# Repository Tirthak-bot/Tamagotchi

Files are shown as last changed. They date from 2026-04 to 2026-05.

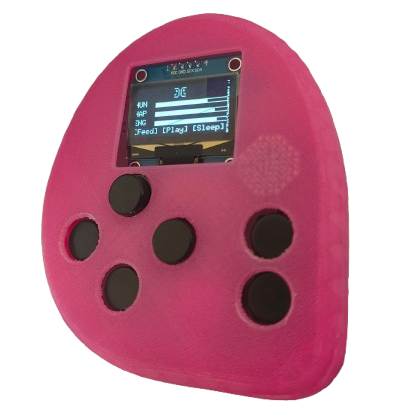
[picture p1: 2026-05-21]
Renders/IRL Images/IMG_20260521_132635066-removebg-preview.png

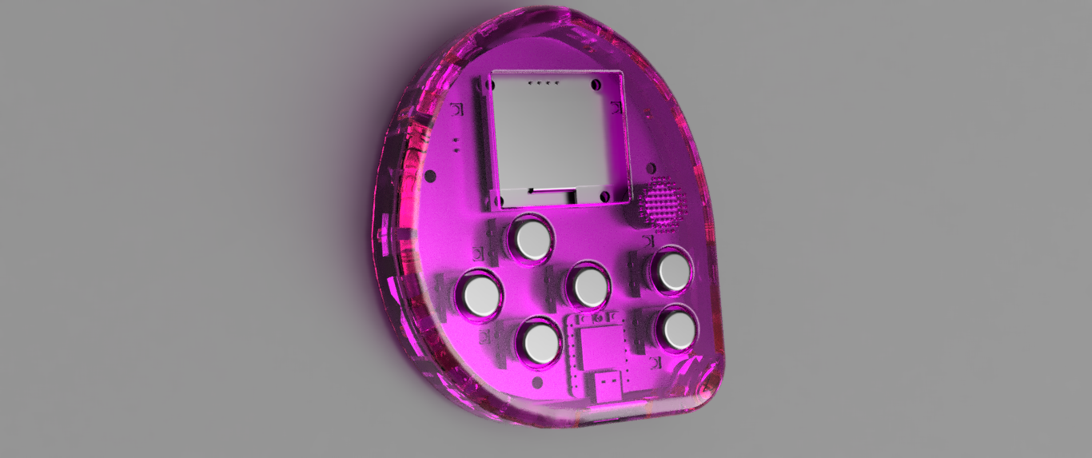
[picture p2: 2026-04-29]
Renders/Render 2.png

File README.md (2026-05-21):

# Tamagotchi

A Custom Tanmagotchi made using The Xiao ESP32 C3. <br>
Designed in KiCad and Fusion 360!

Beige Pink Retro Game Arcade Poster (1)

<br>
<br>

||IRL IMAGES||
|----|----|----|
|IMG_20260521_132635066-removebg-preview| | IMG_20260520_202827706 (1)|

||RENDERS||
|----|----|----|
|Render 1 edited | Render 2 edited | Render 4 edited |

<br>
The irl build looks a bit weird because i couldn't get my hands on the PCB so i had to handwire it sobbbb.
 <br>
 <br>
Using this is pretty straight forward, connect the Tamagotchi to Arduino IDE, Select the board as Xiao ESP32 C3 and Flash the Firmware! 
<br>
The Battery on this should last around 15 hrs :>
<br>
<br>
I wanna build a Tamagotchi because i never had one and what's the fun in buying one!
<br>
<br> 
Demo Video: https://youtube.com/shorts/sFA_lzHIbYA?feature=share

# Schematic
Tamagotchi Schematic

# PCB
Tamagotchi PCB

# Case

The two halfs of the case are joined using magnets and the PCB is screwed into the Bottom case using M3 screws.

Render 5

# Firmware

The firmware is written in C++ and will be edited/deployed from Arduino IDE.

# BOM

| SR.NO | ITEM | QUANTITY | UNIT PRICE | TOTAL PRICE | URL |
|---|---|---|---|---|---|
|1.|Xiao ESP32 C3|1|₹599 ($6.31)|₹650 ($6.85) (Including Shipping)|https://robocraze.com/products/seeed-studio-xiao-esp32c3|
|2.|1.3 inch I2C OLED Display|1|₹320 ($3.38)|₹370 ($3.90) (Including Shipping)|https://robu.in/product/1-3-inch-i2c-iic-oled-lcd-module-4pin-with-vcc-gnd-white|
|3.|12x12x7.3mm Tactile Push Button|10 (Required 6 but MOQ 10)|₹5.5 ($0.058)|₹55 ($0.58) (Shipping Already included above)|https://robu.in/product/12x12x7-3mm-tactile-push-button-switch-10pcs/|
|4.|12 x 9.5mm 3V Active Electromagnetic Buzzer|1|₹14 ($0.15)|₹14 ($0.15) (Shipping Already included above)|https://robu.in/product/3v-active-electromagnetic-buzzer-pack-of-5/|
|5.|1000mAh Rechargeable 3.7v LiPo Battery|1|₹311 ($3.28)|₹311 ($3.28) (Shipping Already included above)|https://robocraze.com/products/witty-fox-1000mah-rechargeable-3-7v-lipo-battery|
|6.|SK6812-MINI-E Neopixel LEDs|8|0 (Self Sourced)|0 (Self Sourced)|LCSC Part #C5149201|
|7.|40x2 Pin 2.54mm Pitch Male Berg Strip (To Connect Stuff ofc)|1|₹10 ($0.11)|₹10 ($0.11) (Shipping Already included above)|https://robocraze.com/products/40x2-pin-2-54mm-pitch-male-berg-strip|
|8.|12x12x7.3 mm Round Cap for Square tactile Switch|6|₹3 ($0.032)|₹18 ($0.19) (Shipping Already included above)|https://robu.in/product/12x12x7-3-mm-round-cap-for-square-tactile-switch|
|9.|M3x6 mm Brass Heat Set Inserts|25 (Required 3 but MOQ 25)|₹4.8 ($0.05)| ₹145 ($1.52) (Including shipping and tax|https://onlyscrews.in/products/m3-x-6mm-3d-printing-brass-threaded-inserts-dia-3mm-length-6mm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|
|10.|M3 Hex Screw Set|1|₹240 ($2.52)|₹265 ($2.80) (Including shipping and tax)|https://onlyscrews.in/products/m3-allen-button-head-ss304-assorted-box?variant=50368948863289|
|11.|3X3 mm Round Magnets N35|25|₹9.5 ($0.10)|₹260 ($2.73) (Including shipping and tax)|https://onlyscrews.in/products/3mm-x-3mm-neodymium-disc-magnets-n35-dia-3mm-thickness-3mm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| 
|12.|Lanyard|1|0 (Self Sourced)| 0 (Self Sourced)|https://amzn.in/d/03Kt7OoU|
|13.|Solder Wire 60/40 - 50gm|1|₹219 ($2.31)|₹219 ($2.31) (Shipping Already included above)|https://robocraze.com/products/noel-solder-wire-60-40-50gm-pack|
|14.|3D Printed Case|1|-| ₹50 ($0.53) in Filament (Around 50gms)|I own a 3D Printer yayaya (Will Print it in Pink PLA Translucent)|
|15.|Super Glue (To Stick The Magnets To The Case)|-|0 (Self Sourced)| 0 (Self Sourced)|https://amzn.in/d/032gD5EX|
|16.|PCB (From Aivon PCB)|5 (MOQ)|$0.20| $2.00 (Including Shipping)|In my Cart ofc (Hope that the Price stays the same sobb)|
|17.|Hex Allen Ket Set|1|₹248 ($2.60)|₹275 ($2.90) (Including tax and shipping)|https://onlyscrews.in/products/eastman-9-pcs-hex-allen-key-set?variant=51184779362617|
|||||||
||TOTAL|||₹2850 ($30.00) (Including all taxes and shipping)|

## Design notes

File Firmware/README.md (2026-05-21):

# Firmware
So this uses the U8g2 library for the display, not the normal Adafruit SSD1306 library as i was having some problems with it. <br>
You install it in Arduino IDE like any other library :)

<br>


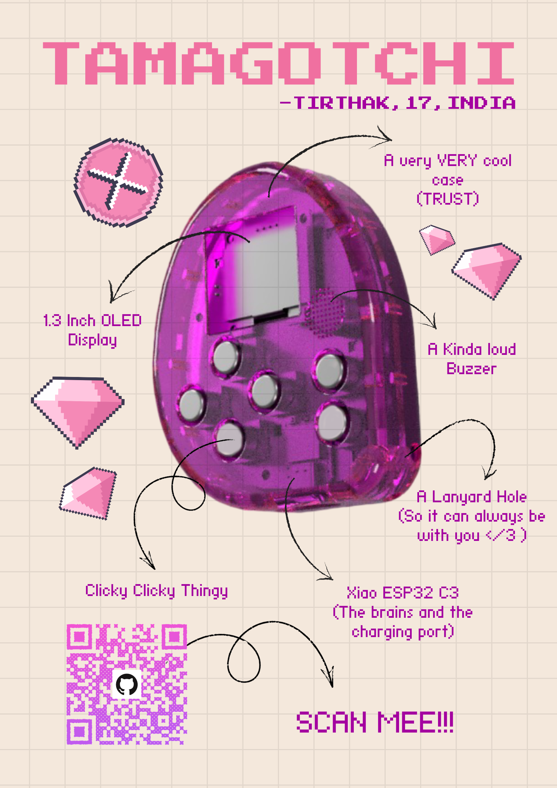
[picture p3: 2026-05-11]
Renders/Tamagotchi Zine Page With Render.png

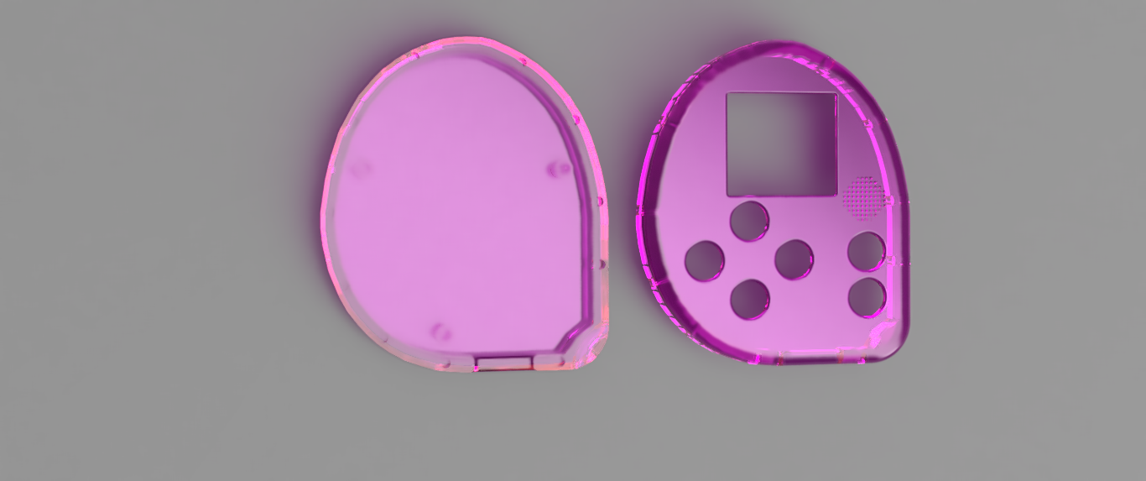
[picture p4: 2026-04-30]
Renders/Render 5.PNG

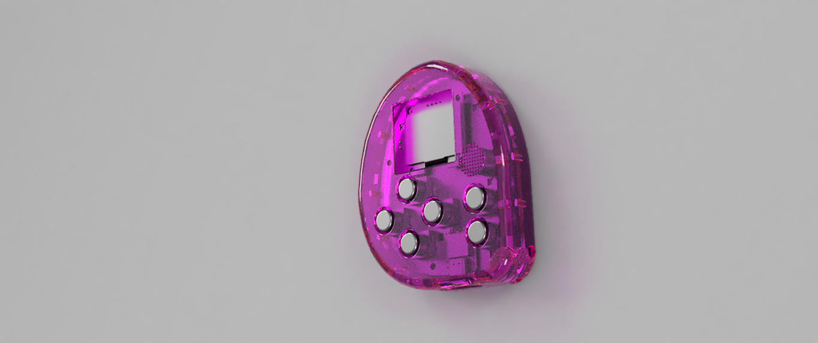
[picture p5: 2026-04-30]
Renders/Render 4.png

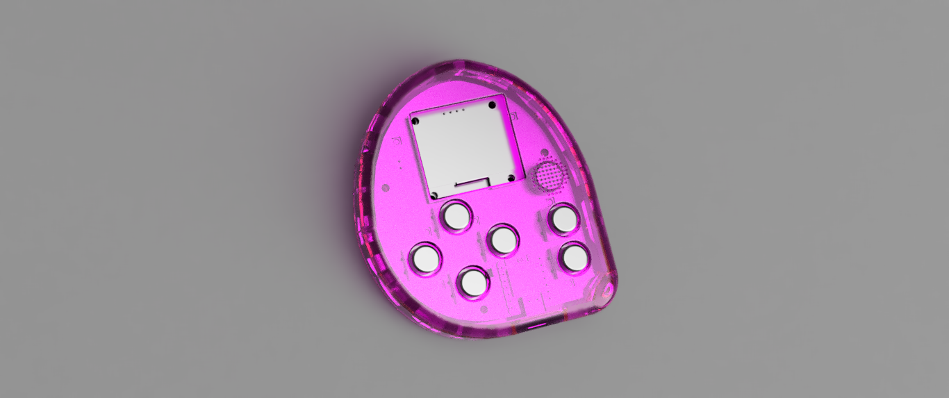
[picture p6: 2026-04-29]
Renders/Render 3.PNG

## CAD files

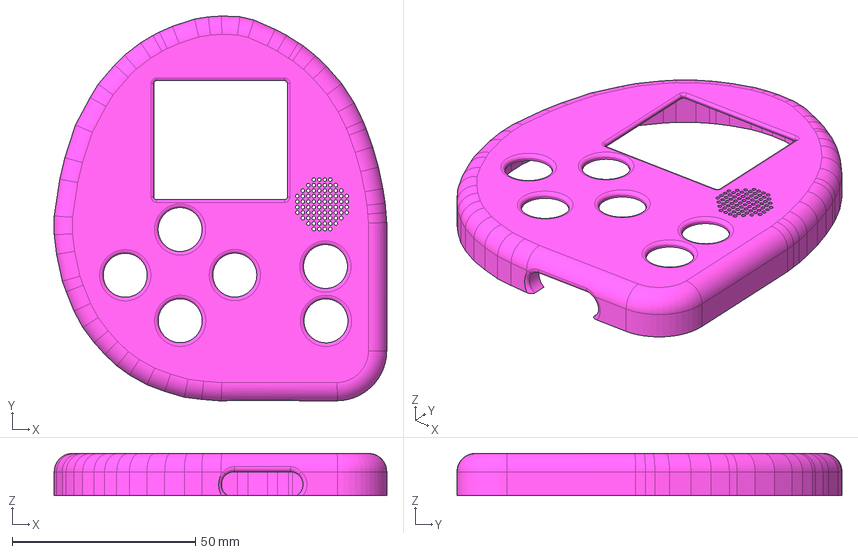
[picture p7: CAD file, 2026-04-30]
CAD/Tamagotchi Case Top.step
90.8 x 105.1 x 11.5 mm

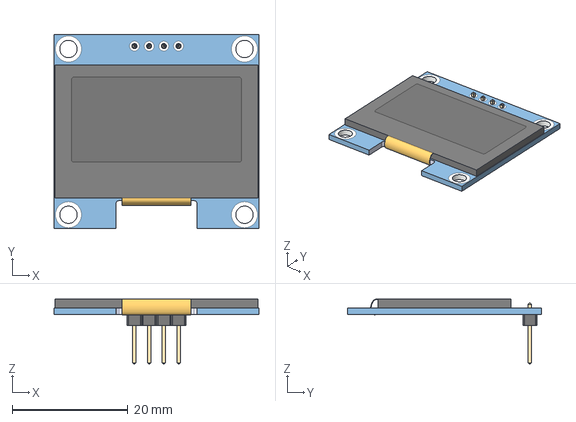
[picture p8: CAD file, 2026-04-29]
Project Resources/1.3 Inch OLED/1.3 Inch OLED 3D Model.stp
35.4 x 33.5 x 11.2 mm

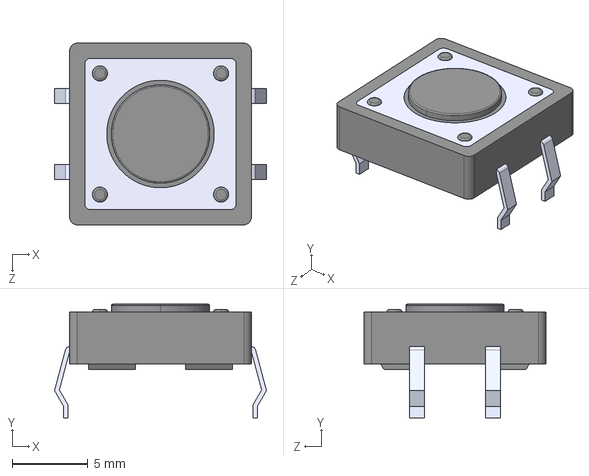
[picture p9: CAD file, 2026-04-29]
Project Resources/12mm x 12mm Tactile Buttons/VS-1213-67-160GF.step
14.0 x 7.50 x 12.0 mm

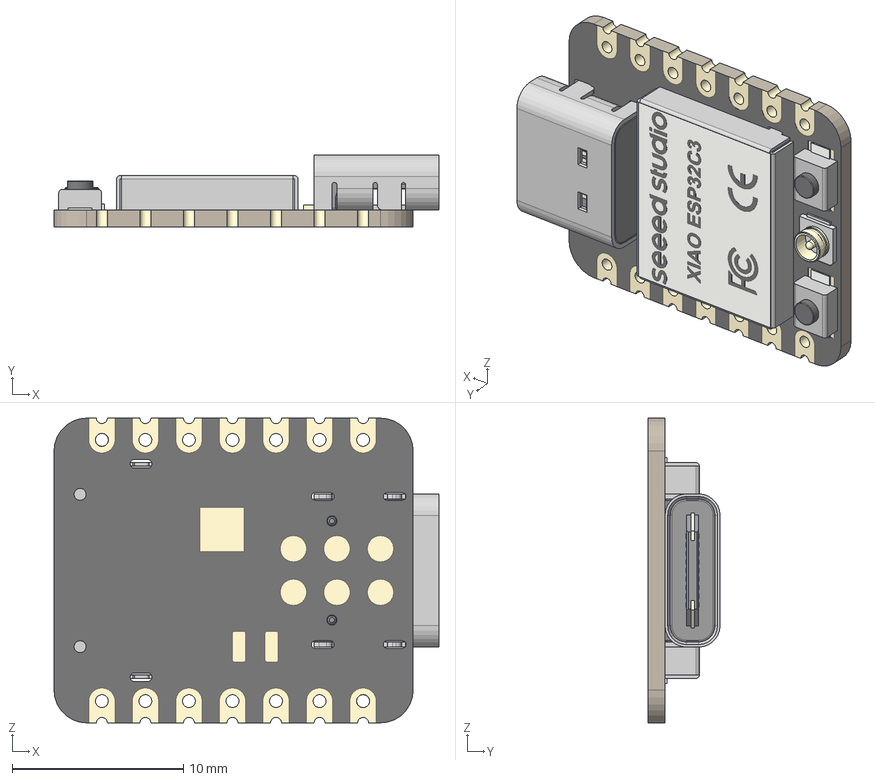
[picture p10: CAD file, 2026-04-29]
Project Resources/Xiao ESP32 C3/seeed-studio-xiao-esp32-c3.step
22.5 x 4.21 x 17.8 mm
BOSS-EXTRUDE14_8_
BOSS-EXTRUDE7_4_
BOSS-EXTRUDE7_3_
BOSS-EXTRUDE14_4_
BOSS-EXTRUDE14_2_
BOSS-EXTRUDE14_11_
BOSS-EXTRUDE7_7_
BOSS-EXTRUDE14_9_
BOSS-EXTRUDE14_3_
BOSS-EXTRUDE14_7_
MIRROR2
BOSS-EXTRUDE14_5_
BOSS-EXTRUDE14_12_
BOSS-EXTRUDE7_8_
BOSS-EXTRUDE7_1_
BOSS-EXTRUDE14_10_
BOSS-EXTRUDE7_9_
BOSS-EXTRUDE14_6_
BOSS-EXTRUDE14_1_
BOSS-EXTRUDE7_6_
BOSS-EXTRUDE7_2_
CUT-EXTRUDE5
BOSS-EXTRUDE7_5_
U.FL Connector v1
Button (1) x 2
Shield

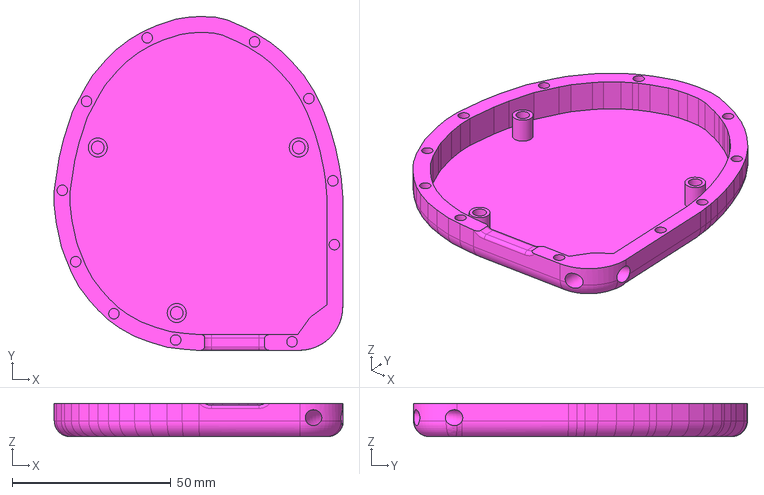
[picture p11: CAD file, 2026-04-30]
CAD/Tamagotchi Case Bottom.step
90.8 x 105.1 x 10.5 mm

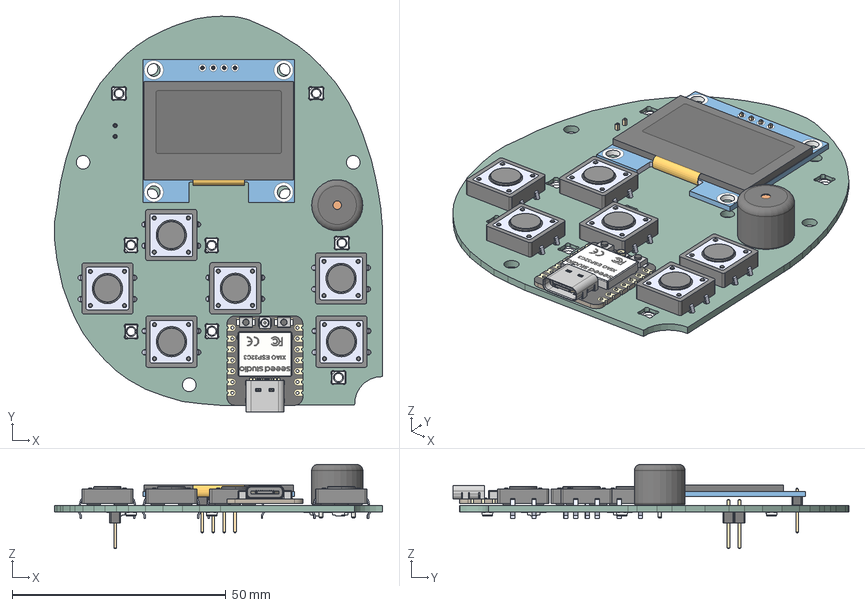
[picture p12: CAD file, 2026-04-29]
CAD/Tamagotchi PCB.step
76.8 x 92.6 x 19.8 mm
SK6812MINI-E--3DModel-STEP-418109 x 8
VS-1213-67-160GF x 6
Buzzer_12x9.5RM7.6
BOSS-EXTRUDE14_8_
BOSS-EXTRUDE7_4_
BOSS-EXTRUDE7_3_
BOSS-EXTRUDE14_4_
BOSS-EXTRUDE14_2_
BOSS-EXTRUDE14_11_
BOSS-EXTRUDE7_7_
BOSS-EXTRUDE14_9_
BOSS-EXTRUDE14_3_
BOSS-EXTRUDE14_7_
MIRROR2
BOSS-EXTRUDE14_5_
BOSS-EXTRUDE14_12_
BOSS-EXTRUDE7_8_
BOSS-EXTRUDE7_1_
BOSS-EXTRUDE14_10_
BOSS-EXTRUDE7_9_
BOSS-EXTRUDE14_6_
BOSS-EXTRUDE14_1_
BOSS-EXTRUDE7_6_
BOSS-EXTRUDE7_2_
CUT-EXTRUDE5
BOSS-EXTRUDE7_5_
U.FL Connector v1
Button (1) x 2
Shield
AZ-Delivery - OLED13 IIC
PinHeader_1x02_P2.54mm_Vertical
Tamagotchi_PCB

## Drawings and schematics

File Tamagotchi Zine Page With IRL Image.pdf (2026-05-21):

# TAMAGOTCHI

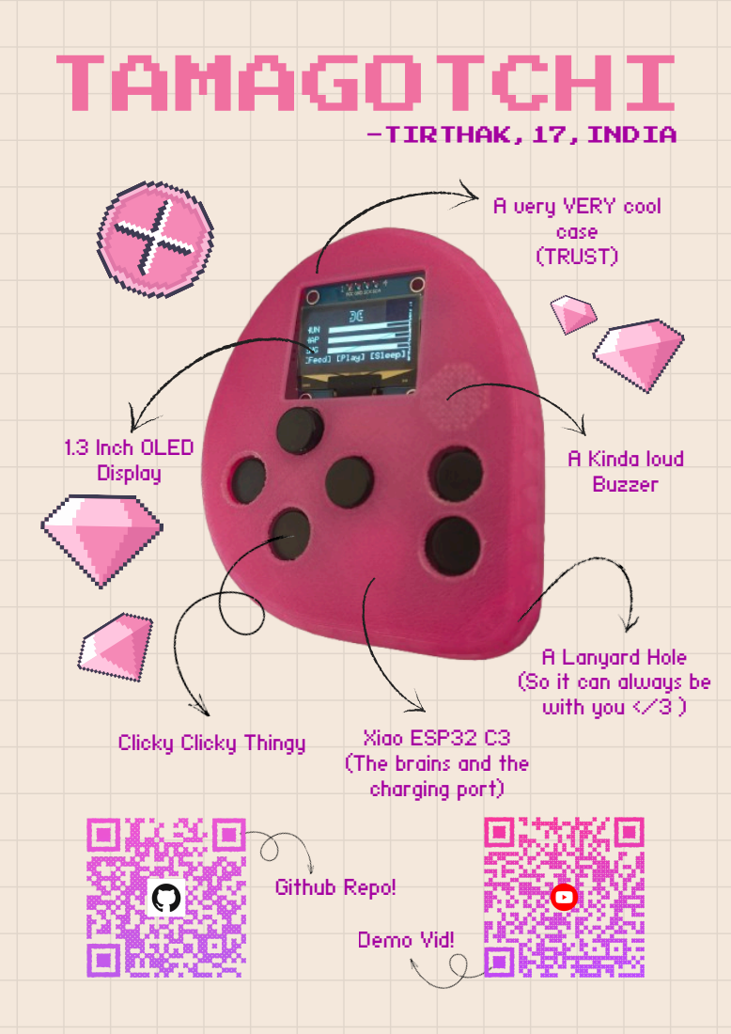
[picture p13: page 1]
1.3 Inch OLED Display; A Kinda loud Buzzer; Clicky Clicky Thingy; Xiao ESP32 C3; Github Repo!; -TIRTHAK,17,INDIA; Demo Vid!

A very VERY cool
case
(TRUST)

A Lanyard Hole
(So it can always be
with you </3 )

(The brains and the
charging port)

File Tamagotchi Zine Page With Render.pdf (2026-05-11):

# TAMAGOTCHI

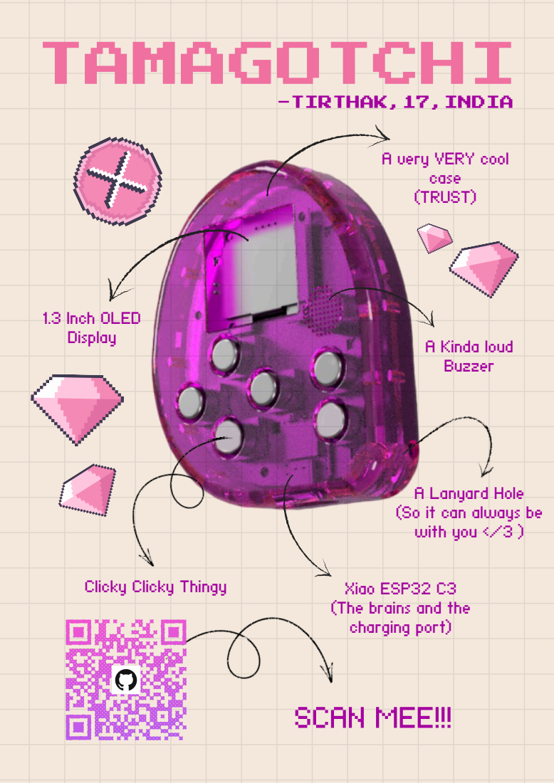
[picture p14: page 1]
1.3 Inch OLED; Display; A Kinda loud; Buzzer; Clicky Clicky Thingy; Xiao ESP32 C3; SCAN MEE!!!; -TIRTHAK,17,INDIA

A very VERY cool
case
(TRUST)

A Lanyard Hole
(So it can always be
with you </3 )

(The brains and the
charging port)

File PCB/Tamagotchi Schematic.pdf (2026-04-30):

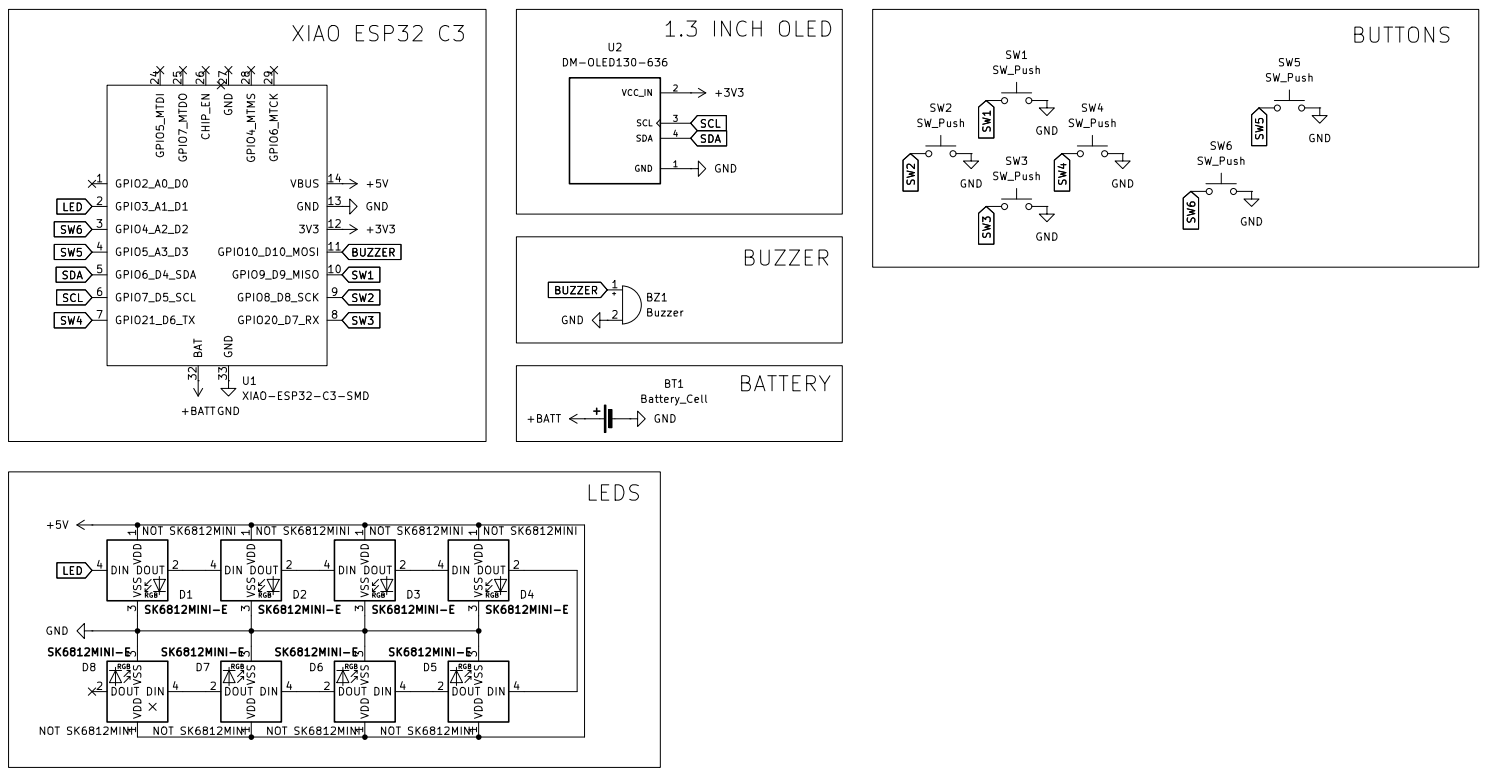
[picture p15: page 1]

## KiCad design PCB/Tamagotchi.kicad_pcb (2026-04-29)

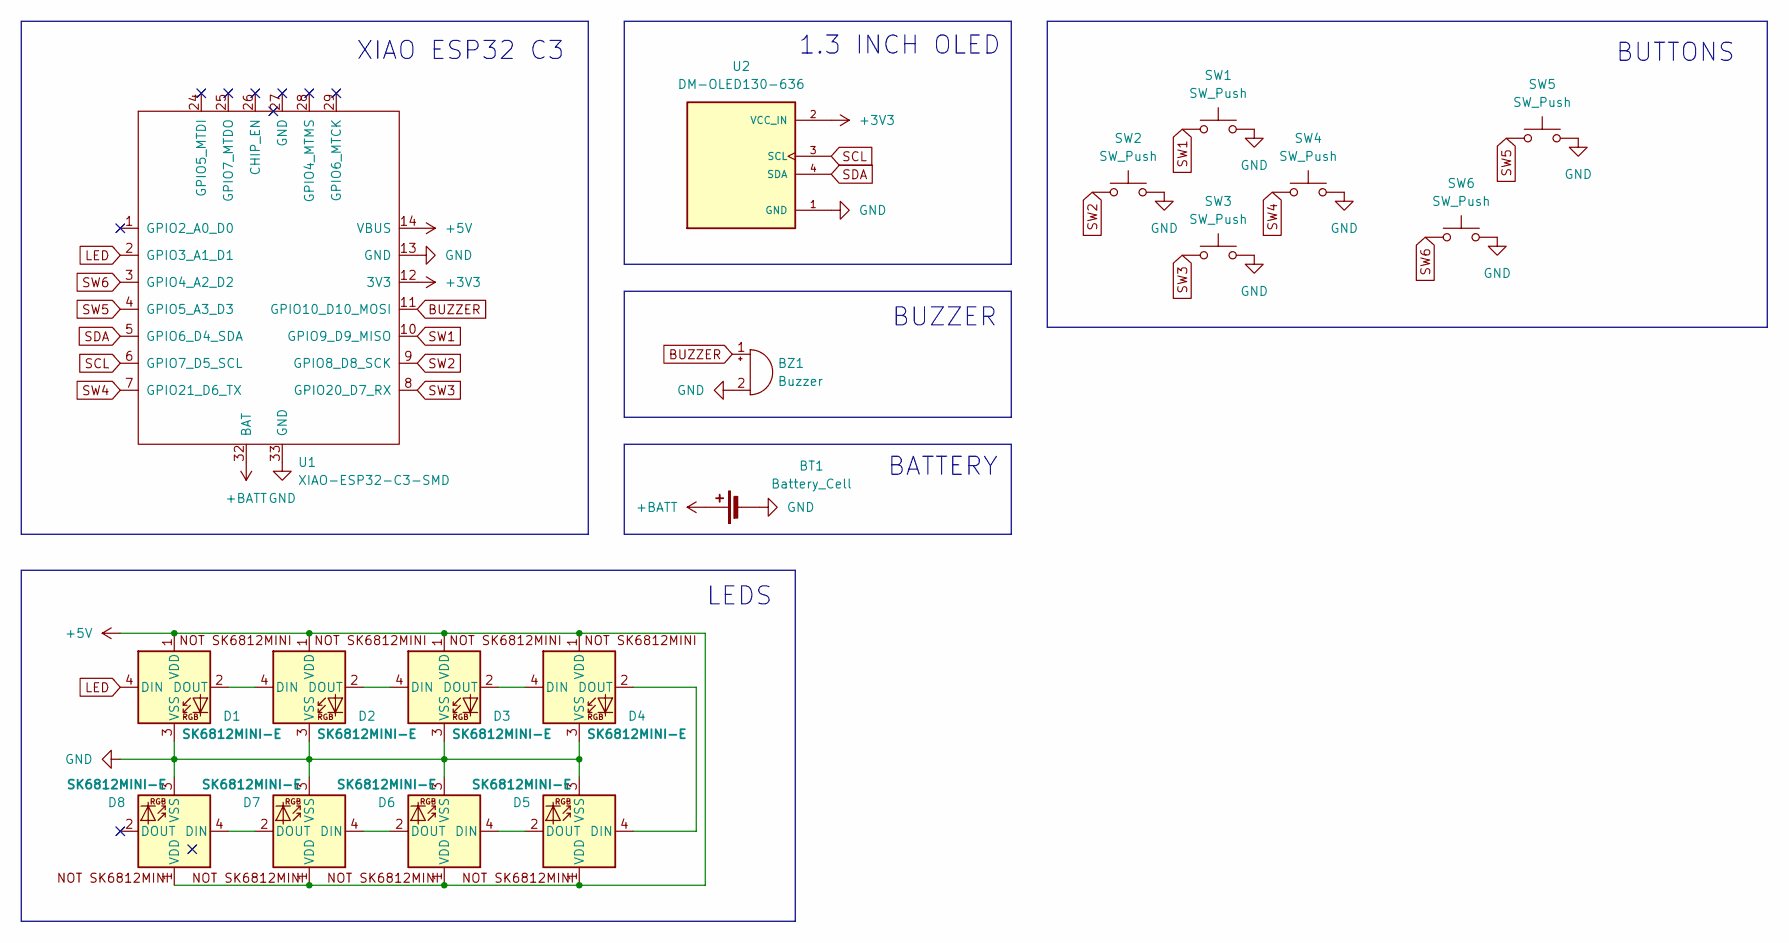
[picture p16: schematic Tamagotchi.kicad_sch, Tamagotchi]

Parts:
BT1: Battery_Cell; PinHeader_1x02_P2.54mm_Vertical
BZ1: Buzzer; Buzzer_12x9.5RM7.6
D1, D2, D3, D4, D5, D6, D7, D8: SK6812MINI-E; SK6812MINI-E_fixed
SW1, SW2, SW3, SW4, SW5, SW6: SW_Push; SW_VS-1213-67-160GF
U1: XIAO-ESP32-C3-SMD; XIAO-ESP32-C3-DIP-SMD
U2: DM-OLED130-636; LCD_OLED_128X64_1.3_I2C; PARTREV 2018-09-10

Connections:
+3V3: U1.12 (3V3), U2.2 (VCC_IN)
+5V: D1.1 (VDD), D2.1 (VDD), D3.1 (VDD), D4.1 (VDD), D5.1 (VDD), D6.1 (VDD), D7.1 (VDD), D8.1 (VDD), U1.14 (VBUS)
+BATT: BT1.1 (+), U1.32 (BAT)
BUZZER: BZ1.1 (+), U1.11 (GPIO10_D10_MOSI)
GND: BT1.2 (-), BZ1.2 (-), D1.3 (VSS), D2.3 (VSS), D3.3 (VSS), D4.3 (VSS), D5.3 (VSS), D6.3 (VSS), D7.3 (VSS), D8.3 (VSS), SW1.2, SW2.2, SW3.2, SW4.2, SW5.2, SW6.2, U1.13 (GND), U1.33 (GND), U2.1 (GND)
LED: D1.4 (DIN), U1.2 (GPIO3_A1_D1)
unnamed: D1.2 (DOUT), D2.4 (DIN)
unnamed: D2.2 (DOUT), D3.4 (DIN)
unnamed: D3.2 (DOUT), D4.4 (DIN)
unnamed: D4.2 (DOUT), D5.4 (DIN)
unnamed: D5.2 (DOUT), D6.4 (DIN)
unnamed: D6.2 (DOUT), D7.4 (DIN)
unnamed: D7.2 (DOUT), D8.4 (DIN)
SCL: U1.6 (GPIO7_D5_SCL), U2.3 (SCL)
SDA: U1.5 (GPIO6_D4_SDA), U2.4 (SDA)
SW1: SW1.1, U1.10 (GPIO9_D9_MISO)
SW2: SW2.1, U1.9 (GPIO8_D8_SCK)
SW3: SW3.1, U1.8 (GPIO20_D7_RX)
SW4: SW4.1, U1.7 (GPIO21_D6_TX)
SW5: SW5.1, U1.4 (GPIO5_A3_D3)
SW6: SW6.1, U1.3 (GPIO4_A2_D2)

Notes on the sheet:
1.3 INCH OLED
BUTTONS
BUZZER
XIAO ESP32 C3
BATTERY
LEDS

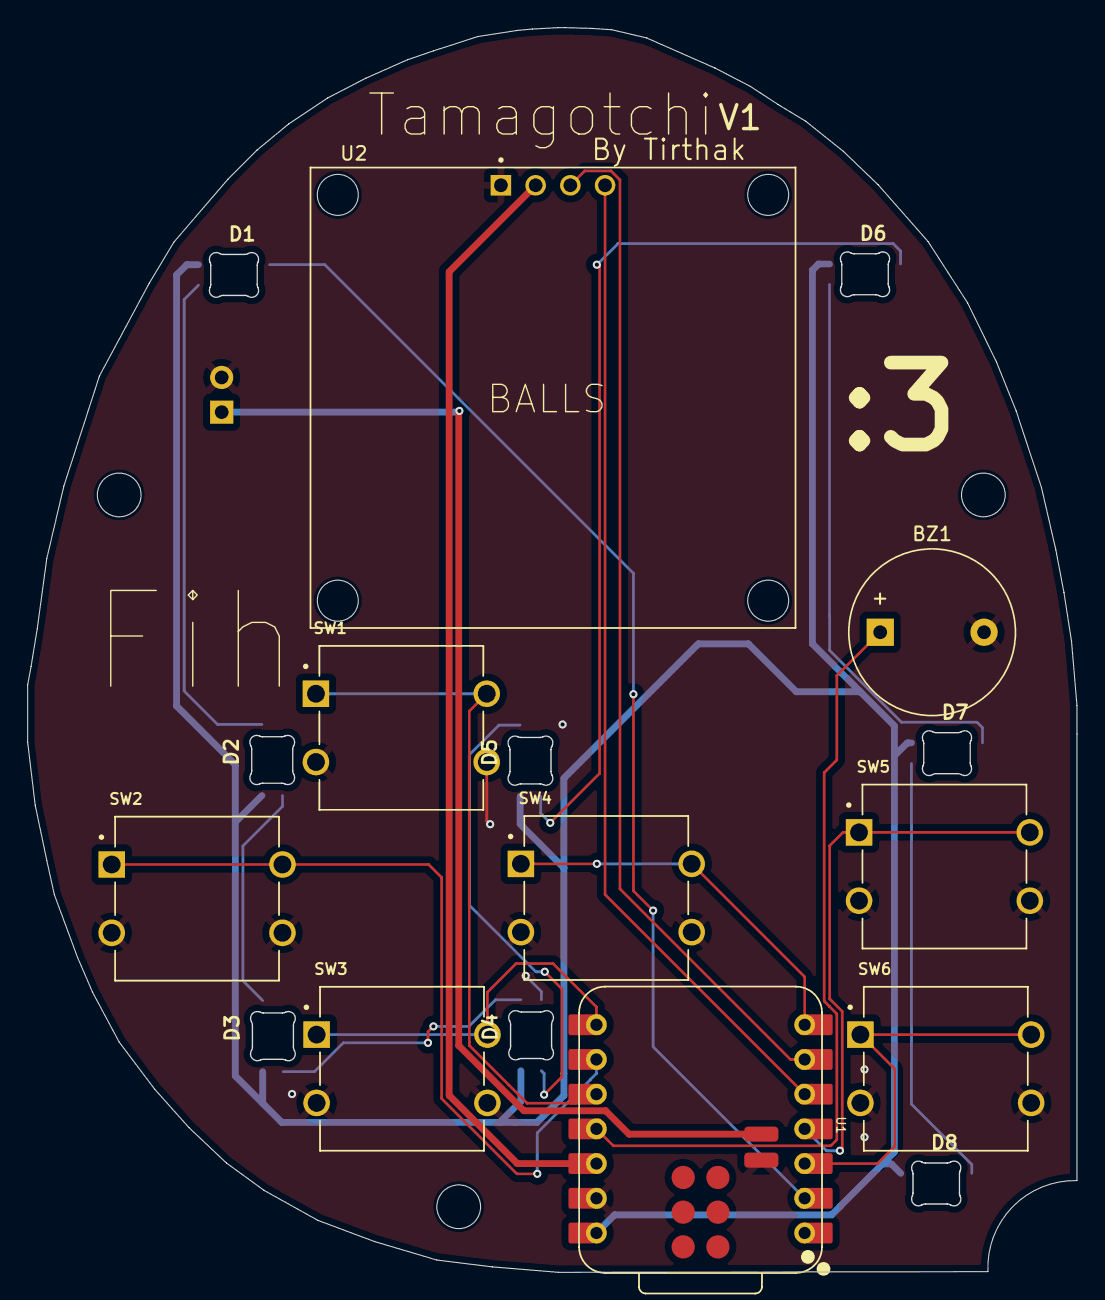
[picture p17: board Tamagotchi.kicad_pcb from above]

Board: 2 copper layers, 76.8 x 91.1 mm, 18 parts (1 on the bottom side), 21 nets.

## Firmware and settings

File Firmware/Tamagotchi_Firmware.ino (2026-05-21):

#include <Wire.h>
#include <U8g2lib.h>

// OLED setup (SSD1306, I2C, full buffer)
U8G2_SSD1306_128X64_NONAME_F_HW_I2C u8g2(U8G2_R0, /* reset=*/ U8X8_PIN_NONE, /* clock=*/7, /* data=*/6);

#define BTN1 9
#define BTN2 8
#define BTN3 20
#define BTN4 21
#define BTN5 5
#define BTN6 4

#define SDA_PIN 6
#define SCL_PIN 7
#define BUZZER 10

#define BTN_UP BTN1
#define BTN_LEFT BTN2
#define BTN_DOWN BTN3
#define BTN_RIGHT BTN4
#define BTN_TOP BTN5
#define BTN_BOTTOM BTN6
#define BUZZER_PIN BUZZER

struct Pet {
  int hunger;
  int happiness;
  int energy;
  unsigned long age;
};
Pet pet;

enum Screen {
  SCREEN_MAIN,
  SCREEN_FEED,
  SCREEN_PLAY,
  SCREEN_SLEEP
};
Screen currentScreen = SCREEN_MAIN;

unsigned long lastUpdate = 0;
unsigned long lastButtonPress = 0;

// --- Bitmaps/emojis (16x16) ---
const unsigned char petHappy[] PROGMEM = {
  0x00,0x00,0x1F,0xF8,0x20,0x04,0x40,0x02,
  0x4C,0x32,0x4C,0x32,0x40,0x02,0x40,0x02,
  0x44,0x22,0x43,0xC2,0x40,0x02,0x20,0x04,
  0x1F,0xF8,0x00,0x00,0x00,0x00,0x00,0x00
};
const unsigned char petSad[] PROGMEM = {
  0x00,0x00,0x1F,0xF8,0x20,0x04,0x40,0x02,
  0x4C,0x32,0x4C,0x32,0x40,0x02,0x40,0x02,
  0x40,0x02,0x43,0xC2,0x44,0x22,0x20,0x04,
  0x1F,0xF8,0x00,0x00,0x00,0x00,0x00,0x00
};
const unsigned char petNeutral[] PROGMEM = {
  0x00,0x00,0x1F,0xF8,0x20,0x04,0x40,0x02,
  0x4C,0x32,0x4C,0x32,0x40,0x02,0x40,0x02,
  0x47,0xE2,0x40,0x02,0x40,0x02,0x20,0x04,
  0x1F,0xF8,0x00,0x00,0x00,0x00,0x00,0x00
};
const unsigned char petSleep[] PROGMEM = {
  0x00,0x00,0x1F,0xF8,0x20,0x04,0x40,0x02,
  0x4F,0x72,0x40,0x02,0x40,0x02,0x40,0x02,
  0x43,0xC2,0x40,0x02,0x40,0x02,0x20,0x04,
  0x1F,0xF8,0x00,0x00,0x00,0x00,0x00,0x00
};

void setup() {
  pinMode(BTN_UP, INPUT_PULLUP);
  pinMode(BTN_LEFT, INPUT_PULLUP);
  pinMode(BTN_DOWN, INPUT_PULLUP);
  pinMode(BTN_RIGHT, INPUT_PULLUP);
  pinMode(BTN_TOP, INPUT_PULLUP);
  pinMode(BTN_BOTTOM, INPUT_PULLUP);
  pinMode(BUZZER_PIN, OUTPUT);

  u8g2.begin();

  pet.hunger = 80;
  pet.happiness = 80;
  pet.energy = 80;
  pet.age = 0;
}

void updatePet() {
  if (millis() - lastUpdate > 5000) {
    pet.hunger = max(0, pet.hunger - 1);
    pet.happiness = max(0, pet.happiness - 1);
    pet.energy = max(0, pet.energy - 1);
    pet.age += 5;
    lastUpdate = millis();
  }
}

void checkButtons() {
  if (millis() - lastButtonPress < 200) return;

  if (digitalRead(BTN_LEFT) == LOW) { currentScreen = SCREEN_FEED; tone(BUZZER_PIN, 1000, 50); lastButtonPress = millis(); }
  else if (digitalRead(BTN_UP) == LOW) { currentScreen = SCREEN_PLAY; tone(BUZZER_PIN, 1200, 50); lastButtonPress = millis(); }
  else if (digitalRead(BTN_RIGHT) == LOW) { currentScreen = SCREEN_SLEEP; tone(BUZZER_PIN, 800, 50); lastButtonPress = millis(); }
  else if (digitalRead(BTN_DOWN) == LOW) { currentScreen = SCREEN_FEED; tone(BUZZER_PIN, 1200, 50); lastButtonPress = millis(); }
  else if (digitalRead(BTN_TOP) == LOW) { currentScreen = SCREEN_PLAY; tone(BUZZER_PIN, 1400, 50); lastButtonPress = millis(); }
  else if (digitalRead(BTN_BOTTOM) == LOW) { currentScreen = SCREEN_SLEEP; tone(BUZZER_PIN, 1000, 50); lastButtonPress = millis(); }
}

void handleScreenLogic() {
  switch(currentScreen) {
    case SCREEN_FEED: pet.hunger = min(100, pet.hunger + 10); currentScreen = SCREEN_MAIN; break;
    case SCREEN_PLAY: pet.happiness = min(100, pet.happiness + 10); pet.energy = max(0, pet.energy - 5); currentScreen = SCREEN_MAIN; break;
    case SCREEN_SLEEP: pet.energy = min(100, pet.energy + 15); currentScreen = SCREEN_MAIN; break;
    case SCREEN_MAIN: break;
  }
}

void drawBar(int x, int y, int value) {
  int barWidth = 100;
  int barHeight = 6;
  int fillWidth = map(value, 0, 100, 0, barWidth);
  u8g2.drawFrame(x, y, barWidth, barHeight);
  u8g2.drawBox(x, y, fillWidth, barHeight);
}

void render() {
  u8g2.clearBuffer();
  u8g2.setFont(u8g2_font_6x10_tf);

  const unsigned char* sprite;
  if (pet.energy < 30 || pet.hunger < 30 || pet.happiness < 30) sprite = petSad;
  else if (pet.hunger > 50 && pet.happiness > 50 && pet.energy > 50) sprite = petHappy;
  else sprite = petNeutral;

  u8g2.drawXBMP(56, 2, 16, 16, sprite);

  u8g2.setCursor(0, 24); u8g2.print("HUN "); drawBar(30, 20, pet.hunger);
  u8g2.setCursor(0, 36); u8g2.print("HAP "); drawBar(30, 32, pet.happiness);
  u8g2.setCursor(0, 48); u8g2.print("ENG "); drawBar(30, 44, pet.energy);

  u8g2.setCursor(0, 60); u8g2.print("[Feed] [Play] [Sleep]");

  u8g2.sendBuffer();
}

void loop() {
  checkButtons();
  updatePet();
  handleScreenLogic();
  render();
  delay(100);
}

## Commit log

2026-04-29 Added stuff for the 1.3 Inch OLED
    [1.3 Inch OLED 3D Model.stp]
2026-04-29 Added the Xiao stuff
    [seeed-studio-xiao-esp32-c3.step]
2026-04-29 Rename KICAD Symbol (Originaly for 0.96 inch OLED but works for 1.3 too) as.kicad_sym to KICAD Symbol (Originaly for 0.96 inch OLED but works for 1.3 too) .kicad_sym
2026-04-29 Adding the button stuff
    [VS-1213-67-160GF.step]
2026-04-29 Uploading kicad stuff
    [Tamagotchi.kicad_pcb, Tamagotchi.kicad_sch]
2026-04-29 adding gerbers and drill files
    [Tamagotchi-B_Cu.gbr, Tamagotchi-B_Mask.gbr, Tamagotchi-B_Paste.gbr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]
2026-04-29 Adding the PCB .step file
    [Tamagotchi.step]
2026-04-29 Rename Tamagotchi.step to Tamagotchi PCB.step
    [Tamagotchi PCB.step, Tamagotchi.step]
2026-04-29 Tamagotchi PCB .step file
    [Tamagotchi PCB.step]
2026-04-29 Added CAD .step files
    [Tamagotchi Bottom.step, Tamagotchi Top.step]
2026-04-29 Added CAD .f3d file
2026-04-29 Added new case files as i edited some stuff
    [Tamagotchi Case Top.step]
